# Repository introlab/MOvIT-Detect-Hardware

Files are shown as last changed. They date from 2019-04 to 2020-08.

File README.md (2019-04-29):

# MOvIT-Detect-Hardware
Cette repository contient tous les documents de fabrication pour les différents capteurs du système MOvIT+. Le dossier MOvIT CAD contient les fichers CAD en format SOLIDWORKS 2018, et STL. Le dossier MOvIT PCB contient les fichiers Altium de chacun des modules et le dossier MOvIT BOM contient le Bill Of Material des pièces de chacun des circuits imprimés. Les fichiers gerber sont également produits pour chacun des PCB nécessaires au projet.

## Liste de pièces
La liste de pièces est en format .xslx, les numéros de pièces sont ceux de Digi-Key. Les BOM permettent de commander chacun des modules séparément, il faudra commander deux fois le kit d'IMU afin d'avoir un kit complet.

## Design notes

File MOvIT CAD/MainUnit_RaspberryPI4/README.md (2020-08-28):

# CAD
This folder contains all the drawing for the modified version for the raspberryPI 4.
There are 2 differents assembly. The "Assemblage" file displays the first version of the cover. The "Assemblage_clip_down" file displays a second version with additionnal clip down (this version should clip more strongly, but has not been tested yet).

## pcb_hors_tout
This folder contains the drawing to specify the maximum dimension that the pcb over the PI 4 can have.

## pieces_2_print
This folder contains the [stl files to print](https://github.com/introlab/MOvIT-Hardware/tree/dev_raspberryPI4/MOvIT%20CAD/MainUnit_RaspberryPI4/pieces_2_print).

## raspberry-pi-4-model
This folder contains a 3D model of the raspberry PI 4

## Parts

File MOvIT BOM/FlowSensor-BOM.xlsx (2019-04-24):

Index | Quantity | Part Number | Manufacturer Part Number | Description | Customer Reference | Available | Backorder | Unit Price | Extended Price CAD
1 | 1 | CCM1500-ND | RJ45-8N-B | CONN MOD JACK 8P8C R/A UNSHLD | J1 | 1 | 0 | 13.48 | 13.48
2 | 1 | 609-2240-ND | 66951-010LF | CONN RCPT 10POS 0.1 GOLD PCB |  | 1 | 0 | 2.93 | 2.93

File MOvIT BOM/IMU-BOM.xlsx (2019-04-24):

Index | Quantity | Part Number | Manufacturer Part Number | Description | Customer Reference | Available | Backorder | Unit Price | Extended Price CAD
1 | 2 | 399-1169-1-ND | C0805C104M5RACTU | CAP CER 0.1UF 50V X7R 0805 | C1, C2 | 2 | 0 | 0.16 | 0.32
2 | 1 | 478-1330-1-ND | 08055A222JAT2A | CAP CER 2200PF 50V C0G/NP0 0805 | C3 | 1 | 0 | 0.51 | 0.51
3 | 1 | 732-5316-ND | 61300311121 | CONN HEADER VERT 3POS 2.54MM | P1 | 1 | 0 | 0.19 | 0.19
4 | 2 | RR12P10.0KDCT-ND | RR1220P-103-D | RES SMD 10K OHM 0.5% 1/10W 0805 | R1, R2 | 2 | 0 | 0.17 | 0.34
5 | 1 | 380-1043-ND | SS-7066-NF | CONN MOD JACK 6P6C R/A UNSHLD |  | 1 | 0 | 1.06 | 1.06
6 | 1 | 1428-1007-1-ND | MPU-6050 | IMU ACCEL/GYRO 3-AXIS I2C 24QFN | MPU6050 | 1 | 0 | 12.84 | 12.84
1 | 1 | 732-2678-ND | 60900213421 | JUMPER W/TEST PNT 1X2PINS 2.54MM |  | 1 | 0 | 0.46 | 0.46

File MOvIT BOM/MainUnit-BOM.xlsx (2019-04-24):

Index | Quantity | Part Number | Manufacturer Part Number | Description | Customer Reference | Available | Backorder | Unit Price | Extended Price CAD
1 | 1 | 535-11937-1-ND | ABS07-120-32.768KHZ-T | CRYSTAL 32.7680KHZ 6PF SMD |  | 1 | 0 | 0.88 | 0.88
2 | 1 | 399-1169-1-ND | C0805C104M5RACTU | CAP CER 0.1UF 50V X7R 0805 | C1 | 1 | 0 | 0.16 | 0.16
3 | 2 | 311-1095-1-ND | CC0805DRNPO9BN6R0 | CAP CER 6PF 50V C0G/NPO 0805 | Cx1, Cx2 | 2 | 0 | 0.29 | 0.58
4 | 2 | H11267-ND | TM2RE-2424(50) | CONN MOD JACK 6P6C VERT UNSHLD | J1, J2 | 2 | 0 | 15.56 | 31.12
5 | 1 | CCM1500-ND | RJ45-8N-B | CONN MOD JACK 8P8C R/A UNSHLD | J3 | 1 | 0 | 13.48 | 13.48
6 | 1 | MCP79410-I/SN-ND | MCP79410-I/SN | IC RTC CLK/CALENDAR I2C 8-SOIC | RTC | 1 | 0 | 1.44 | 1.44
7 | 2 | RR12P10.0KDCT-ND | RR1220P-103-D | RES SMD 10K OHM 0.5% 1/10W 0805 | R1, R2 | 2 | 0 | 0.17 | 0.34
8 | 1 | 952-1745-1-ND | S8411-45R | BATTERY HOLDER COIN 12MM SMD |  | 1 | 0 | 2.09 | 2.09
9 | 1 | S6104-ND | PPTC202LFBN-RC | CONN HDR 40POS 0.1 TIN PCB | P1 | 1 | 0 | 3.32 | 3.32

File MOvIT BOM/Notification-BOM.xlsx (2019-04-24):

Index | Quantity | Part Number | Manufacturer Part Number | Description | Customer Reference | Available | Backorder | Unit Price | Extended Price CAD
1 | 1 | 399-1169-1-ND | C0805C104M5RACTU | CAP CER 0.1UF 50V X7R 0805 | C1 | 1 | 0 | 0.16 | 0.16
2 | 2 | RR12P10.0KDCT-ND | RR1220P-103-D | RES SMD 10K OHM 0.5% 1/10W 0805 | R1, PullUp | 2 | 0 | 0.17 | 0.34
3 | 1 | 350-3134-ND | 5532212100F | LED CBI 3MM BI-LVL RED/GRN TINT |  | 1 | 0 | 2.38 | 2.38
4 | 1 | 1N4148WTPMSCT-ND | 1N4148W-TP | DIODE GEN PURP 100V 150MA SOD123 |  | 1 | 0 | 0.2 | 0.20
5 | 1 | 360-3265-ND | BB15AH-FA | SWITCH PUSH SPDT 0.4VA 28V |  | 1 | 0 | 6.69 | 6.69
6 | 1 | 1670-1005-ND | C1020B111F | VIBRATION MOTOR COIN 3V WIRE |  | 1 | 0 | 4.45 | 4.45
7 | 1 | MMBT3904LT3GOSCT-ND | MMBT3904LT3G | TRANS NPN 40V 0.2A SOT23 |  | 1 | 0 | 0.2 | 0.20
8 | 1 | 296-20952-1-ND | PCA9536DGKR | IC I/O EXPANDER I2C 4B 8VSSOP |  | 1 | 0 | 2.06 | 2.06
9 | 1 | RR12P390DCT-ND | RR1220P-391-D | RES SMD 390 OHM 0.5% 1/10W 0805 | Rbjt | 1 | 0 | 0.17 | 0.17
10 | 1 | RR12P110DCT-ND | RR1220P-111-D | RES SMD 110 OHM 0.5% 1/10W 0805 | Rled1, Rled2 | 1 | 0 | 0.17 | 0.17
11 | 1 | 380-1043-ND | SS-7066-NF | CONN MOD JACK 6P6C R/A UNSHLD |  | 1 | 0 | 1.06 | 1.06

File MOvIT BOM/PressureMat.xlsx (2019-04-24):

Index | Quantity | Part Number | Manufacturer Part Number | Description | Customer Reference | Available | Backorder | Unit Price | Extended Price CAD
1 | 11 | 399-1169-1-ND | C0805C104M5RACTU | CAP CER 0.1UF 50V X7R 0805 | C1, C2, Cf0 ... Cf8 | 11 | 0 | 0.118 | 1.30
2 | 11 | RR12P10.0KDCT-ND | RR1220P-103-D | RES SMD 10K OHM 0.5% 1/10W 0805 | Pull Up, Rd0 … Rd8 | 11 | 0 | 0.151 | 1.66
3 | 1 | 380-1043-ND | SS-7066-NF | CONN MOD JACK 6P6C R/A UNSHLD |  | 1 | 0 | 1.06 | 1.06
4 | 1 | 609-3526-ND | 71922-220LF | CONN HEADER R/A 20POS 2.54MM |  | 1 | 0 | 2.73 | 2.73
5 | 1 | MAX11611EEE+-ND | MAX11611EEE+ | IC ADC SERIAL 10BIT 12CH 16-QSOP |  | 1 | 0 | 7.39 | 7.39
6 | 10 | RR12P33.0KDCT-ND | RR1220P-333-D | RES SMD 33K OHM 0.5% 1/10W 0805 | Rf0 ... Rf8, Rref | 10 | 0 | 0.151 | 1.51

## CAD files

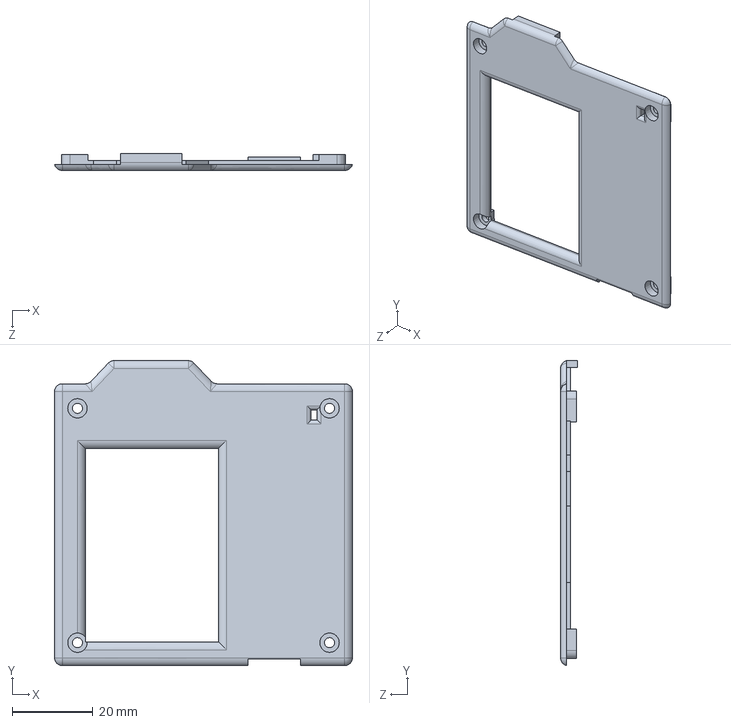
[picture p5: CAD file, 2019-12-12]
MOvIT CAD/MainUnit/MainUnit-TOP.sldprt
74.0 x 75.8 x 4.20 mm

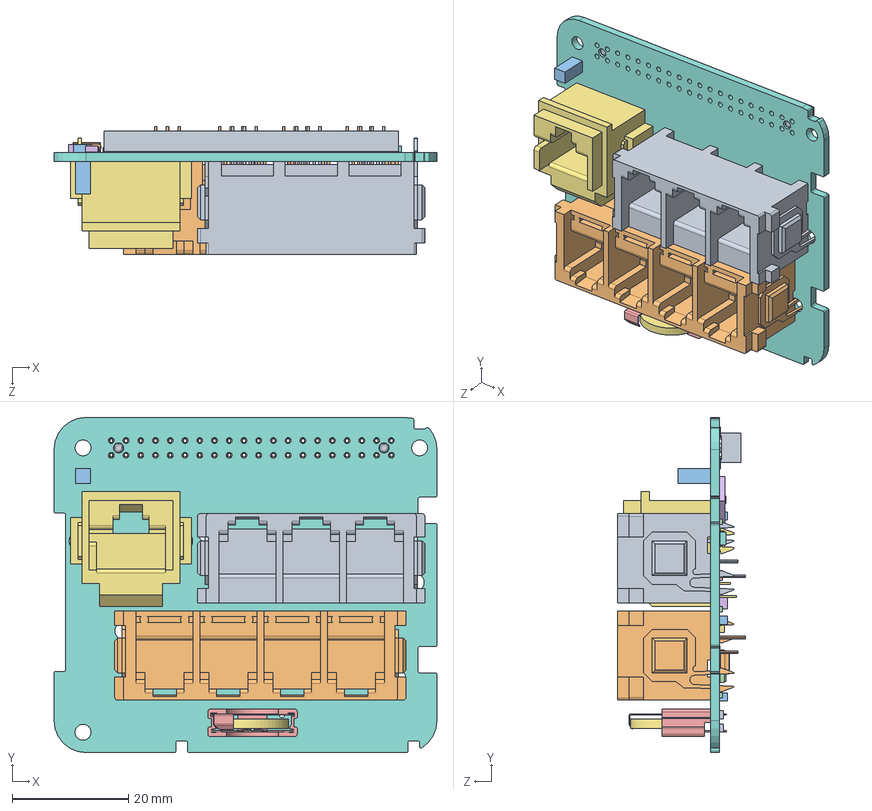
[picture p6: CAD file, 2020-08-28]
MOvIT CAD/MainUnit_RaspberryPI4/Mainboard_Rpi4.SLDASM
66.0 x 57.7 x 22.0 mm
M20-78120_MOULD.step
M20-781_CONTACT.step x 40
Extruded.step x 3
Extruded-0.step x 10
Extruded-1.step
Extruded-2.step
TM3RA-88_RGB13278208.step
Extruded-3.step x 7
Extruded-4.step x 2
Open_CASCADE_STEP_translator_6.8_10.2.1.step
Open_CASCADE_STEP_translator_6.8_10.1.step
Leader.step x 8
BS-1225-PC.step
Extruded-5.step x 2
Body-6.step
bigPin.step x 2
TM2RE-1818(50).step
TM2RE-2424_RGB13278208.step
Extruded-7.step
Extruded-8.step x 16
Extruded-9.step x 2
Extruded-10.step
Cylinder.step
Board.step

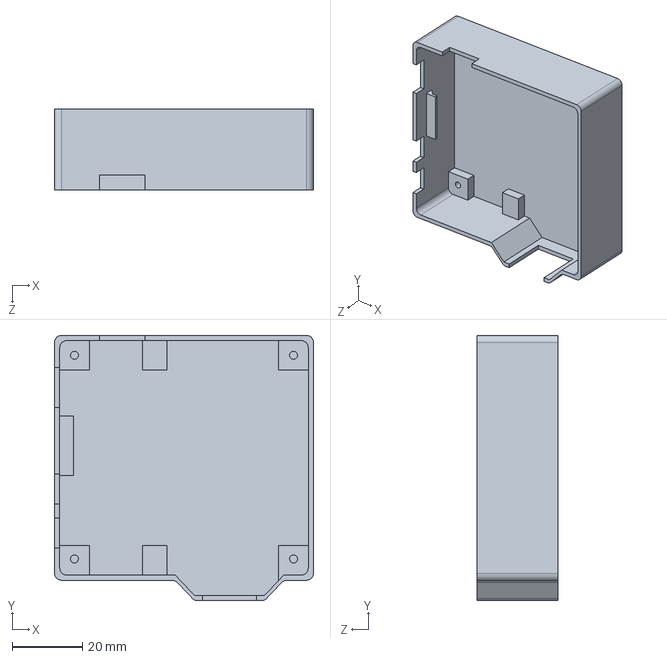
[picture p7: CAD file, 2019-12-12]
MOvIT CAD/MainUnit/MainUnit-BOTTOM.SLDPRT
74.0 x 75.8 x 23.0 mm

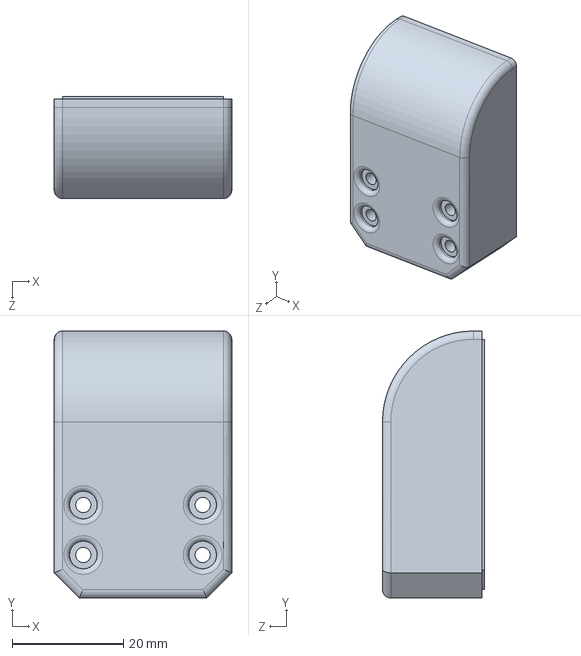
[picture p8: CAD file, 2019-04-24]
MOvIT CAD/Flow sensor/Flow-TOP.SLDPRT
32.0 x 48.1 x 18.4 mm

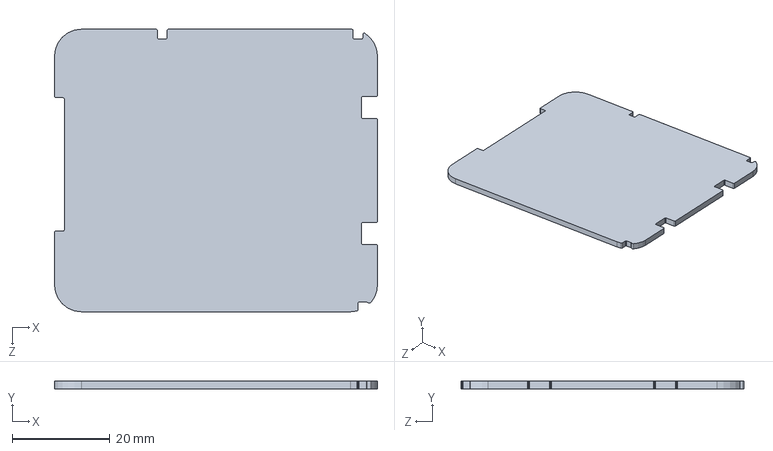
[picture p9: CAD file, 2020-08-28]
MOvIT CAD/MainUnit_RaspberryPI4/pcb_hors_tout/PCB_horsTout.SLDPRT
66.0 x 1.60 x 57.8 mm

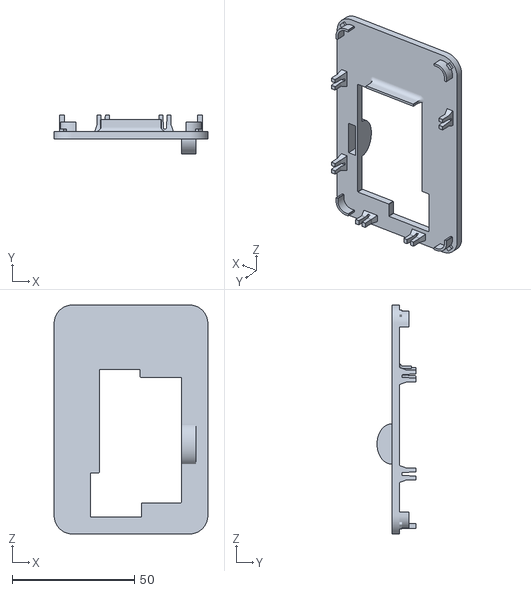
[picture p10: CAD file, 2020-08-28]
MOvIT CAD/MainUnit_RaspberryPI4/pieces_2_print/RPI4_Canakit_cover_complet.STL
62.7 x 15.9 x 93.5

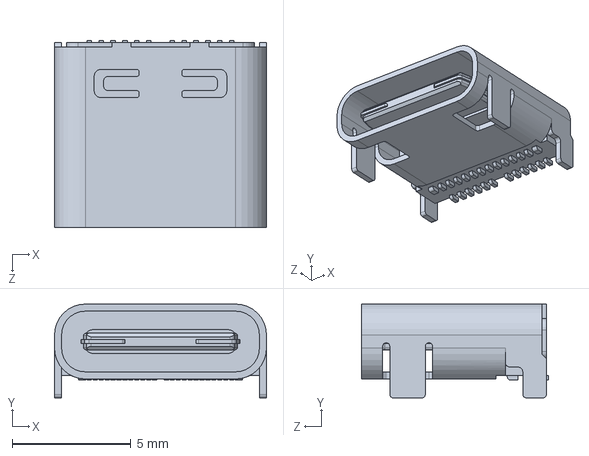
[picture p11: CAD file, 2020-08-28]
MOvIT CAD/MainUnit_RaspberryPI4/raspberry-pi-4-model/Female USB Type C Connector, RPi4ModelB.SLDPRT
8.94 x 3.96 x 7.90 mm

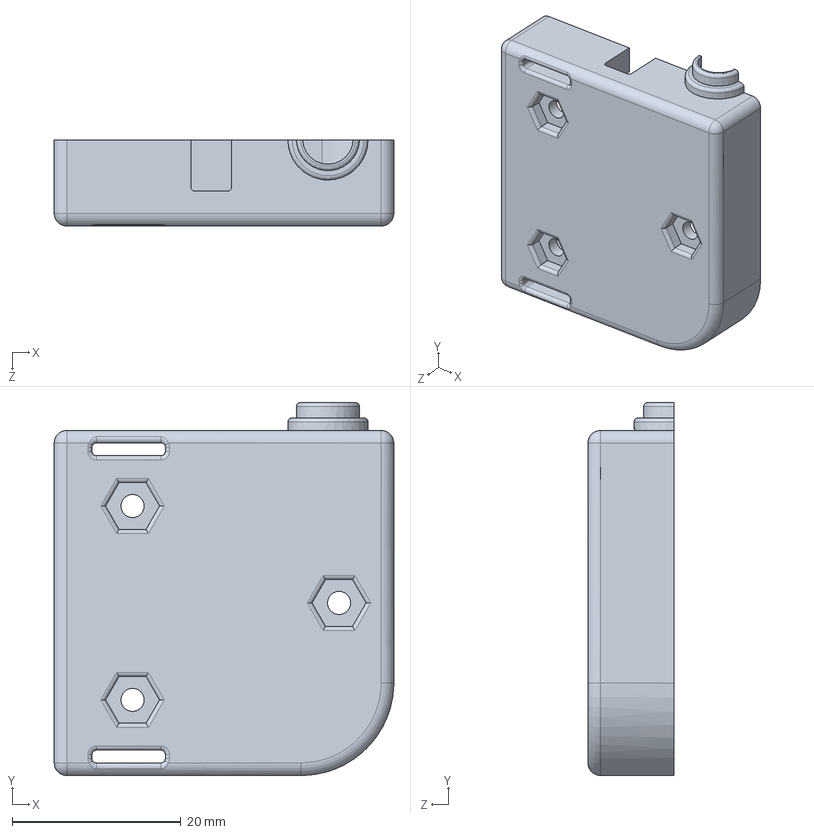
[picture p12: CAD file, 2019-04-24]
MOvIT CAD/Notification/Notification-RIGHT.SLDPRT
40.3 x 44.3 x 10.2 mm

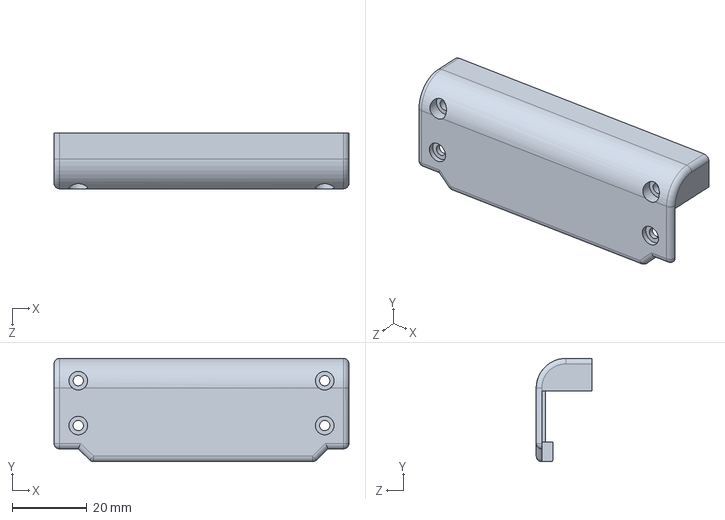
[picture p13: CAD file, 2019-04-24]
MOvIT CAD/PressureMat/Pressure-TOP.SLDPRT
79.0 x 27.7 x 14.9 mm

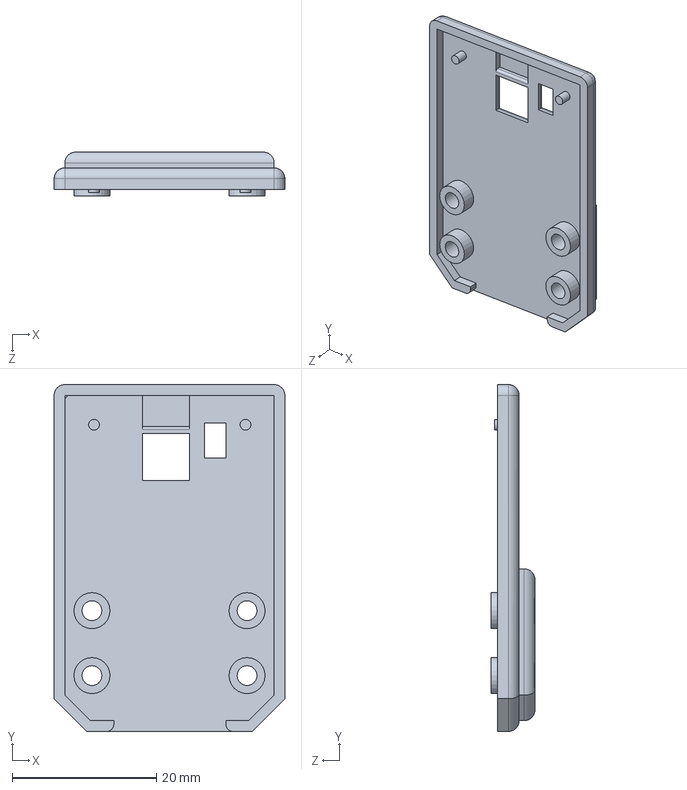
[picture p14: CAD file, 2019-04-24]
MOvIT CAD/Flow sensor/Flow-BOTTOM.SLDPRT
32.0 x 48.1 x 6.10 mm

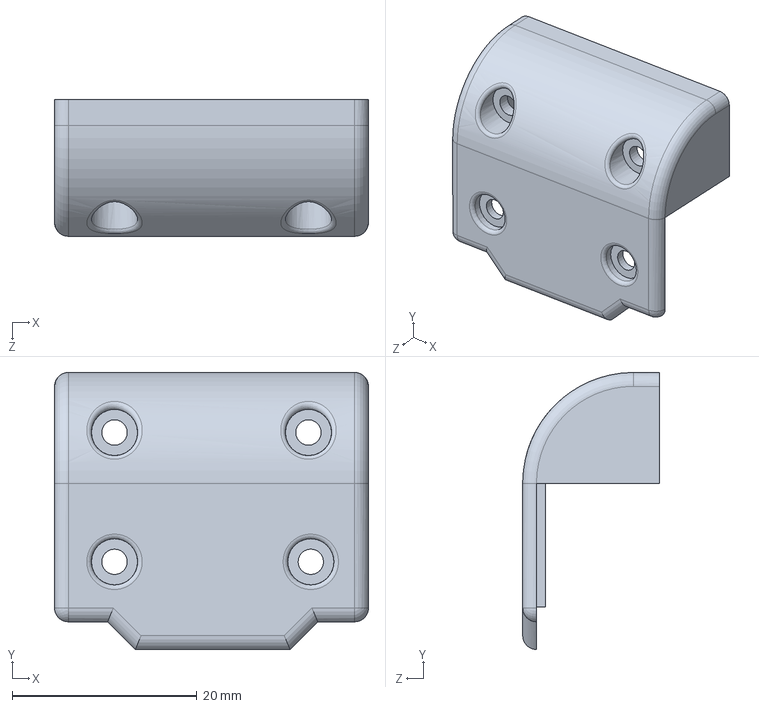
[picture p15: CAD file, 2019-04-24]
MOvIT CAD/IMU/IMU-TOP.SLDPRT
34.0 x 30.0 x 14.8 mm

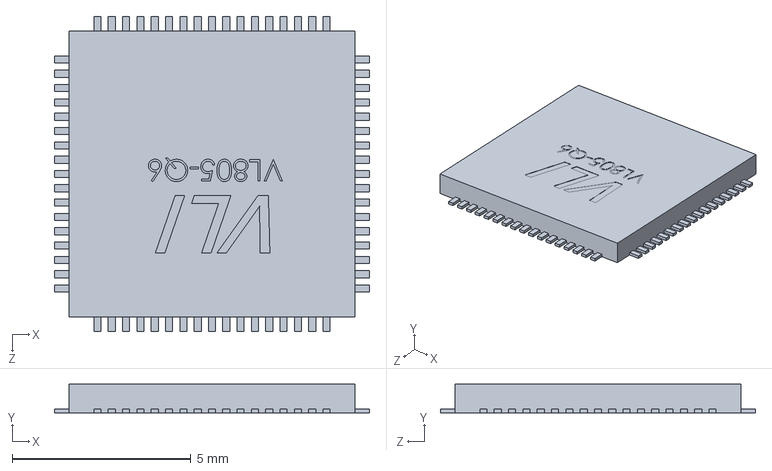
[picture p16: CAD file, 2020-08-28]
MOvIT CAD/MainUnit_RaspberryPI4/raspberry-pi-4-model/VIA VL805 PCIe USB 3.0 controller, RPi4ModelB.SLDPRT
8.80 x 0.8 x 8.80 mm

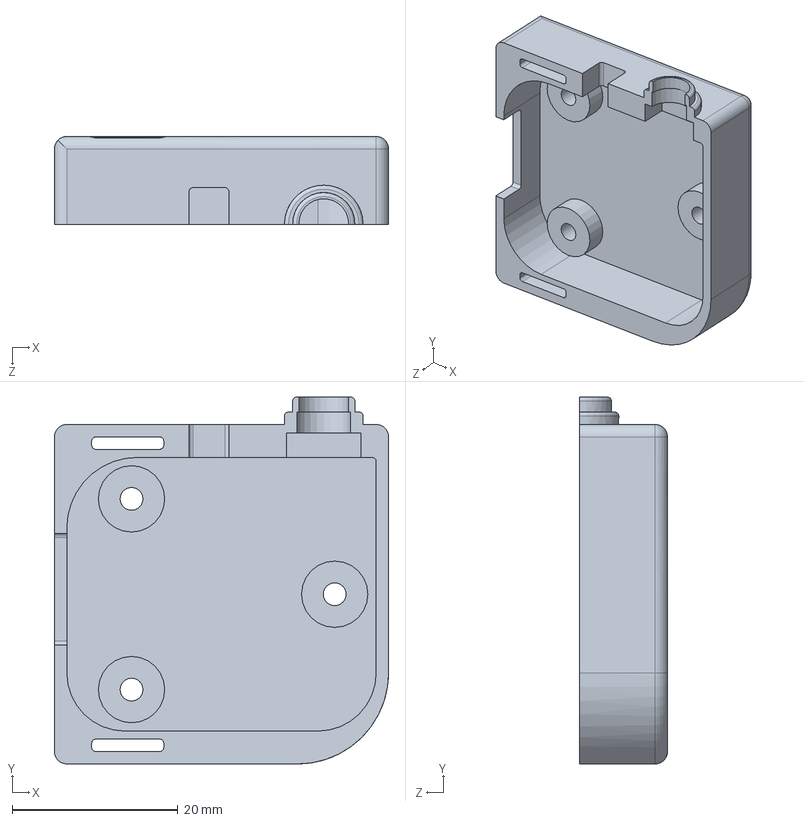
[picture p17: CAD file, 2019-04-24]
MOvIT CAD/Notification/Notification-LEFT.SLDPRT
40.3 x 44.3 x 10.6 mm

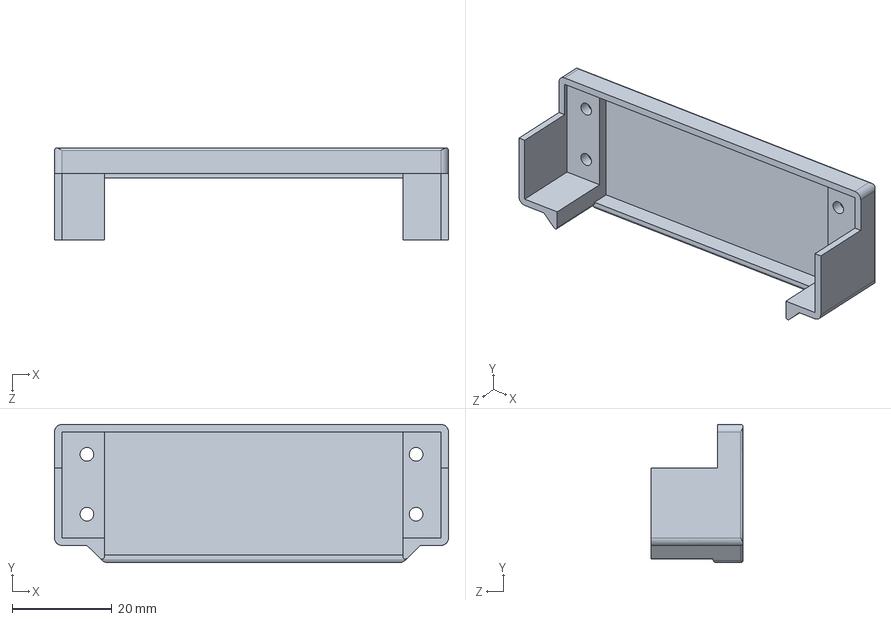
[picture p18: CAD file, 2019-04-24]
MOvIT CAD/PressureMat/Pressure-BOTTOM.SLDPRT
79.0 x 27.7 x 18.5 mm

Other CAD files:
MOvIT CAD/IMU/IMU-BOTTOM.SLDPRT
MOvIT CAD/MainUnit_RaspberryPI4/pieces_2_print/RPI4_Canakit_cover_clip_down_complet.STL
MOvIT CAD/MainUnit_RaspberryPI4/RPI4_Canakit_cover_clip_down.SLDPRT
MOvIT CAD/Flow sensor/STL/Flow-BOTTOM.STL
MOvIT CAD/Flow sensor/STL/Flow-TOP.STL
MOvIT CAD/IMU/STL/IMU-BOTTOM.STL
MOvIT CAD/IMU/STL/IMU-TOP.STL
MOvIT CAD/MainUnit/STL/MainUnit-BOTTOM.STL
MOvIT CAD/MainUnit/STL/MainUnit-TOP.STL
MOvIT CAD/MainUnit_RaspberryPI4/RPI4_Canakit_Case.SLDPRT
MOvIT CAD/MainUnit_RaspberryPI4/RPI4_Canakit_Case.STEP
MOvIT CAD/MainUnit_RaspberryPI4/RPI4_Canakit_cover.SLDPRT
MOvIT CAD/MainUnit_RaspberryPI4/pcb_hors_tout/PCB_horsTout.DXF
MOvIT CAD/MainUnit_RaspberryPI4/pcb_hors_tout/PCB_horsTout.SLDDRW
MOvIT CAD/MainUnit_RaspberryPI4/pieces_2_print/RPI4_Canakit_cover_battery_protector.stl
MOvIT CAD/MainUnit_RaspberryPI4/pieces_2_print/RPI4_Canakit_cover_clip_down_plain.STL
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

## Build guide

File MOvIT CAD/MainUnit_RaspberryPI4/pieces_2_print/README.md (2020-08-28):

# There is 2 differents version of the cover
The first version has been tested and works fine. The "clip_down" version should hold on more, but has not been tested.

# Printing specification
Because of the shape of the cover, it will be easier to print in 2 parts (and glue them with acetone). Simply print one of the "plain" file and the "battery_protector" file.

If you directly want the full cover, just print one of the "complet" file.

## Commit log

2019-04-24 Ajout des fichier de fabrication de PCB, CAD et BOM
    [Flow-BOTTOM.SLDPRT, Flow-BOTTOM.STL, Flow-TOP.SLDPRT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]
2019-04-29 Ajout des fichiers gerber
    [FlowSensor.GBL, FlowSensor.GBS, FlowSensor.GKO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]
2019-12-12 Update CAD of MainUnit
    [MainUnit-BOTTOM.SLDPRT, MainUnit-BOTTOM.STL, MainUnit-TOP.STL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]
2020-04-16 Initial branch creation
    [2.54 mm DUPONT MALE PIN HEADER, IO, 2X20, RPi4ModelB.SLDPRT, 2.54 mm DUPONT MALE PIN HEADER, IO, 2X40, RPi4ModelB.SLDPRT, 2.54 mm DUPONT MALE PIN HEADER, POE, 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]
2020-04-16 try for steadier clip
    [PCB_horsTout.DXF, PCB_horsTout.SLDDRW, PCB_horsTout.SLDPRT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]
2020-08-25 Modified form factor for Rpi4 + added "switches" to individual expansion ports
    [RaspberryPi.PcbDoc, RaspberryPi.PrjPcb, RaspberryPi.SchDoc]
2020-08-25 Added missing schematic file
    [Disconnects.SchDoc]
